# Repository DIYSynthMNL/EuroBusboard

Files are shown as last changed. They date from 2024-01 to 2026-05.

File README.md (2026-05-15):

# EuroBusboard

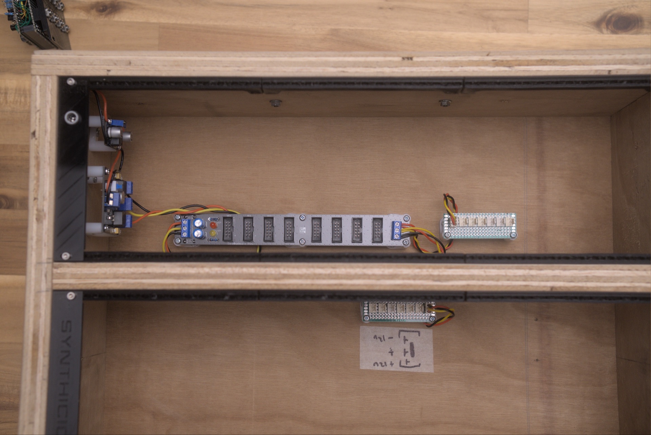
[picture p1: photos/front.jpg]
EuroBusboard installed in case


A Eurorack bus board with **8 module slots**, distributing **±12V + GND** across multiple connector formats. The project has three PCB variants in the same KiCad project: **10-pin IDC + JST combined**, **10-pin IDC only**, and **JST only**.

> For the Doepfer-standard 16-pin IDC variant (with `+5V`, `CV`, `Gate` rails additionally distributed), see the sibling repo: **[EuroBusboard-8-IDC-16PIN](https://github.com/DIYSynthMNL/EuroBusboard-8-IDC-16PIN)**.

## Variants

The KiCad project contains four configurations. Pick one when fabricating the PCB:

| Variant | KiCad file | Per-slot connectors | Use case |
|---|---|---|---|
| **16-pin IDC** (Doepfer A-100) | (in separate repo: [EuroBusboard-8-IDC-16PIN](https://github.com/DIYSynthMNL/EuroBusboard-8-IDC-16PIN)) | 1× 16-pin IDC | Modules with full Doepfer ribbon cables (±12V + GND + +5V + CV + Gate) |
| **10-pin IDC + JST (combined)** | `eurobusboard_idc_jst_8.kicad_pcb` | 1× 10-pin IDC + 1× 3-pin JST | Maximum flexibility — accepts both connector types per slot |
| **10-pin IDC only** | `eurobusboard_idc_8.kicad_pcb` | 1× 10-pin IDC | Compact, IDC-only modules |
| **JST only** | `eurobusboard_jst_8.kicad_pcb` | 1× 3-pin JST | DIY modules that use only the 3-pin JST power input |

All variants share the same power-input + reverse-protection + filter section. Only the per-slot connectors differ.

## Pinout (10-pin IDC, Eurorack subset of Doepfer A-100)

Looking at the IDC connector with the keyway (red stripe) on the *bottom*:

```
Pin   10  9   8   7   6   5   4   3   2   1
      +12 +12 GND GND GND GND GND GND -12 -12
```

`-12V` is on pin 1 / 2 (the red-stripe side) — Eurorack convention. `+12V` is on pin 9 / 10 (opposite side). Six GND pins in the middle provide low-impedance ground return.

The **3-pin JST** is:

| JST pin | Net |
|---|---|
| 1 | +12V |
| 2 | GND |
| 3 | -12V |

## Schematic

- Latest: **Rev 0.1** ([EuroBusboard-Schematic-rev0.1.pdf](Schematic%20PDFs/EuroBusboard-Schematic-rev0.1.pdf)) — 3 sheets, one per non-16-pin variant

## Power input / protection

Same circuit on all three sheets, just renamed nets per variant:

```
External ±12V supply
   │
   ├──[D3 / D14 / D9   1N4007 reverse-polarity diode on +12V]──┬── +12V bus
   │                                                            │
   │                                                            [C1 / C7 / C5   100µF bulk cap]
   │                                                            │
   │                                                            [D1 / D13 / D11  +12V indicator LED + R1/R7/R5 10K]
   │
   └──[D4 / D16 / D10  1N4007 reverse-polarity diode on -12V]──┬── -12V bus
                                                                │
                                                                [C2 / C8 / C6   100µF bulk cap]
                                                                │
                                                                [D2 / D15 / D12  -12V indicator LED + R2/R8/R6 10K]
```

Additional features (combined-variant only):
- **Power Thru** (J20, J21) — daisy-chain to another bus board
- **Test points** TP1 (+12V), TP2 (GND), TP3 (-12V) for DMM probing

## Design notes

**1N4007 diodes have a real voltage drop.** At a peak transient current of 1 A across each rail (with all 8 modules pulling momentarily), the diode drops about **1.0 V** — modules see only ~11 V on the rail instead of 12 V. For most analog modules this is harmless; for tight regulators (e.g. an LM7805 regulating to +5V from +12V supply that's actually 11V), it can reduce headroom. **A 1N5817 Schottky (~0.4 V drop)** would be a near-drop-in upgrade. See [issue](../../issues).

**No +5V or CV/Gate rails.** The 10-pin IDC variants don't distribute +5V (which most digital modules need) or CV/Gate (which the Doepfer A-100 standard provides for keyboard-bus signals). Modules requiring +5V must generate their own (via a 78M05 + the +12V rail — which is what most DIYSynthMNL modules do). For full Doepfer compatibility, use the 16-pin IDC variant in [EuroBusboard-8-IDC-16PIN](https://github.com/DIYSynthMNL/EuroBusboard-8-IDC-16PIN).

**Bulk capacitance.** 100 µF at the input is reasonable for a small case. For a fully-loaded board with current-hungry modules (digital sequencers, OLEDs, several VCAs), consider adding ~10 µF ceramics near each IDC connector for transient suppression.

## License

[GPLv3](LICENSE) — strong copyleft. **Note:** this is different from most DIYSynthMNL modules (which use CC-BY-NC-SA 4.0 for hardware, MIT for firmware). Confirm this license is intentional — for a passive bus board, MIT or CC-BY-SA may be more appropriate. See [issue](../../issues).

## Build status

What's ready for builders today, and what's still on the TODO list:

- [x] Schematic — Rev 0.1 ([EuroBusboard-Schematic-rev0.1.pdf](Schematic%20PDFs/EuroBusboard-Schematic-rev0.1.pdf))
- [ ] PCB layout — in progress — four variants in `kicad/`, no rev marker yet
- [ ] Gerber files for fabrication — none yet
- [ ] BOM — bus boards are simple; the schematic doubles as the BOM (LED color, diode replacement to Schottky if you take the recommendation above, etc.)
- [x] Photos of an assembled board — see [photos/](photos/)
- [x] License — [LICENSE](LICENSE) (GPLv3 — see note above)

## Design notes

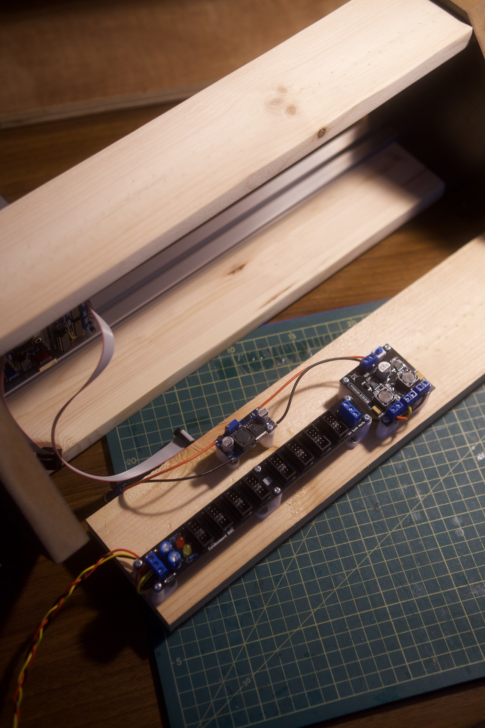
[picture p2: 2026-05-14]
photos/bench-4.jpg

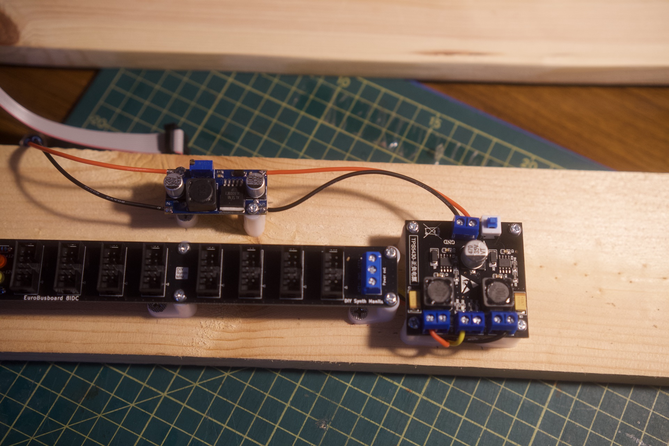
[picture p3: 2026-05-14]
photos/bench-with-psu.jpg

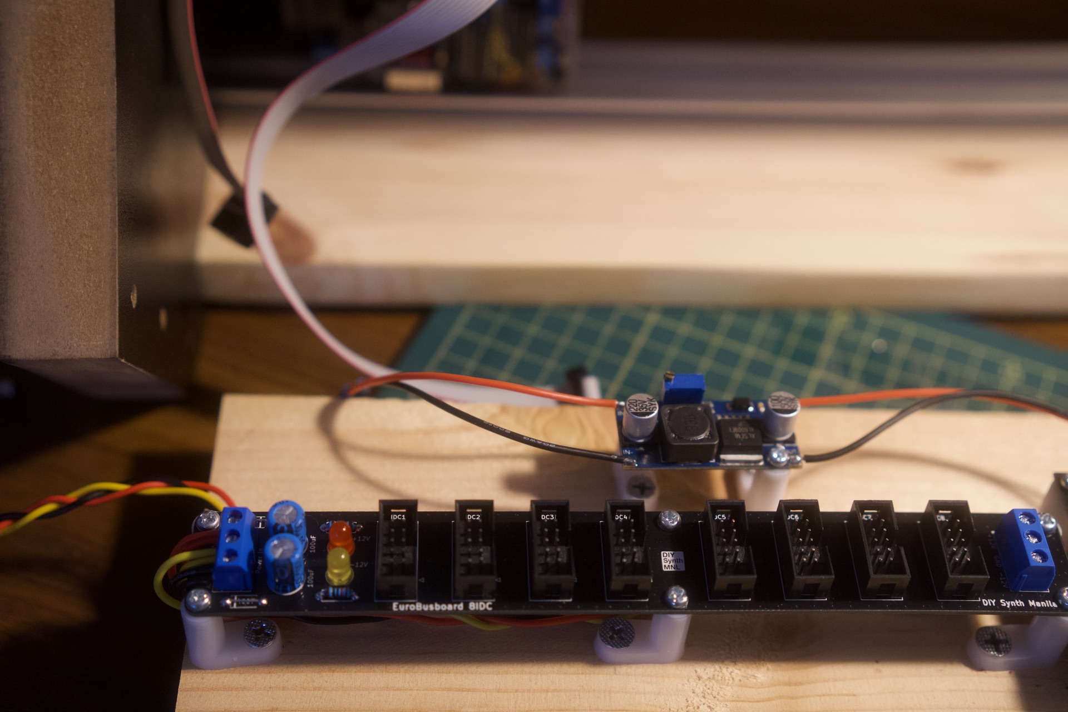
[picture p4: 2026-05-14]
photos/bench-3.jpg

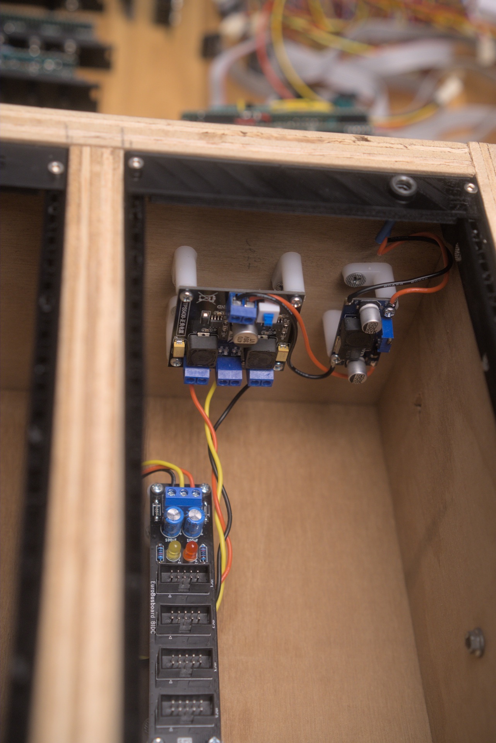
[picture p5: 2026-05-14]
photos/in-case-detail.jpg

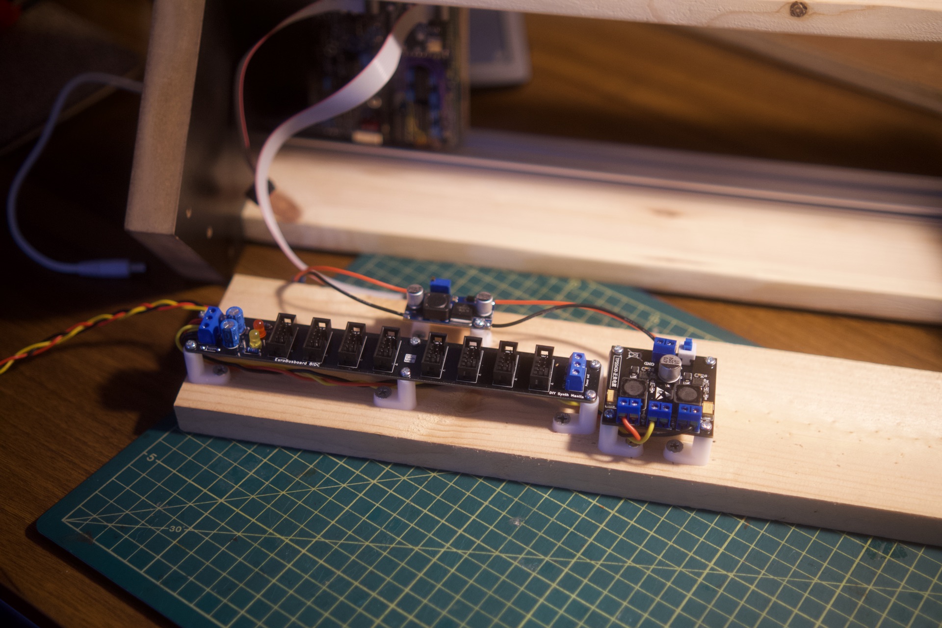
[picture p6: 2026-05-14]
photos/bench-1.jpg

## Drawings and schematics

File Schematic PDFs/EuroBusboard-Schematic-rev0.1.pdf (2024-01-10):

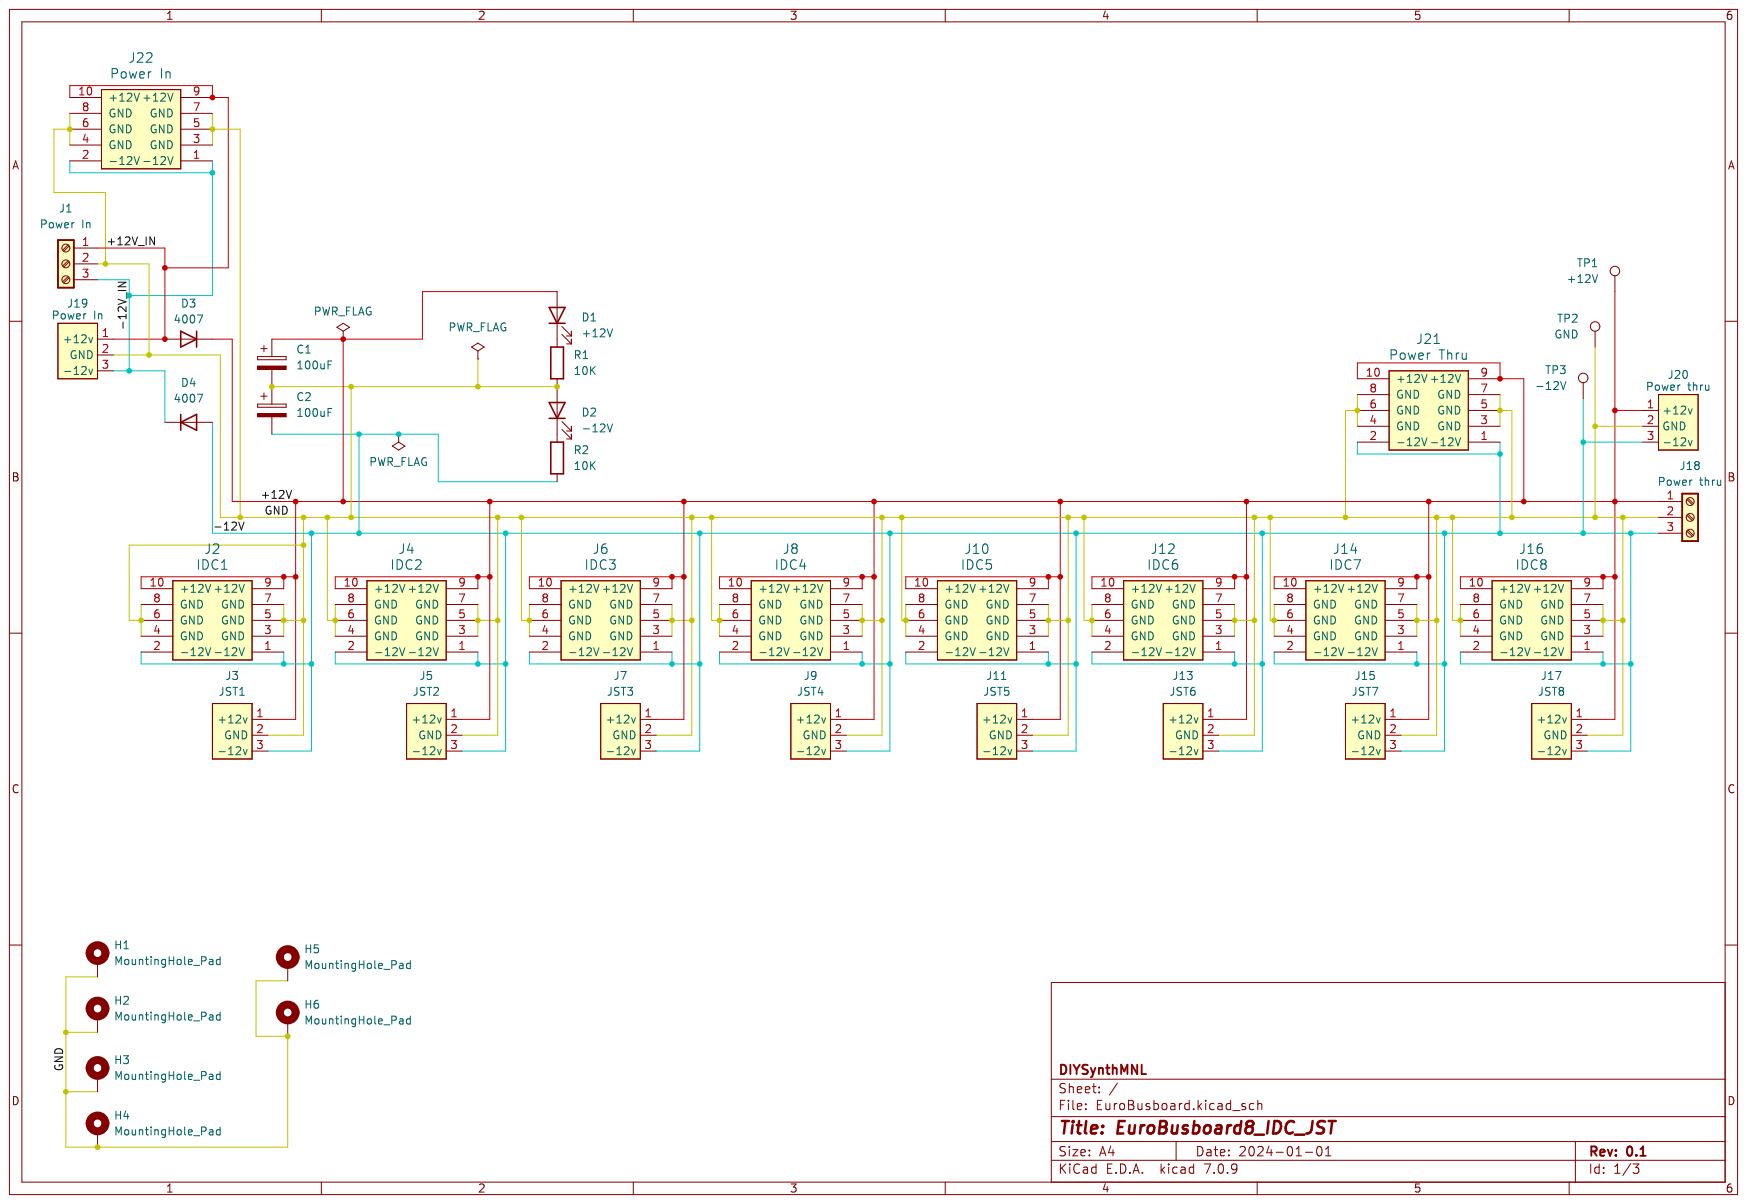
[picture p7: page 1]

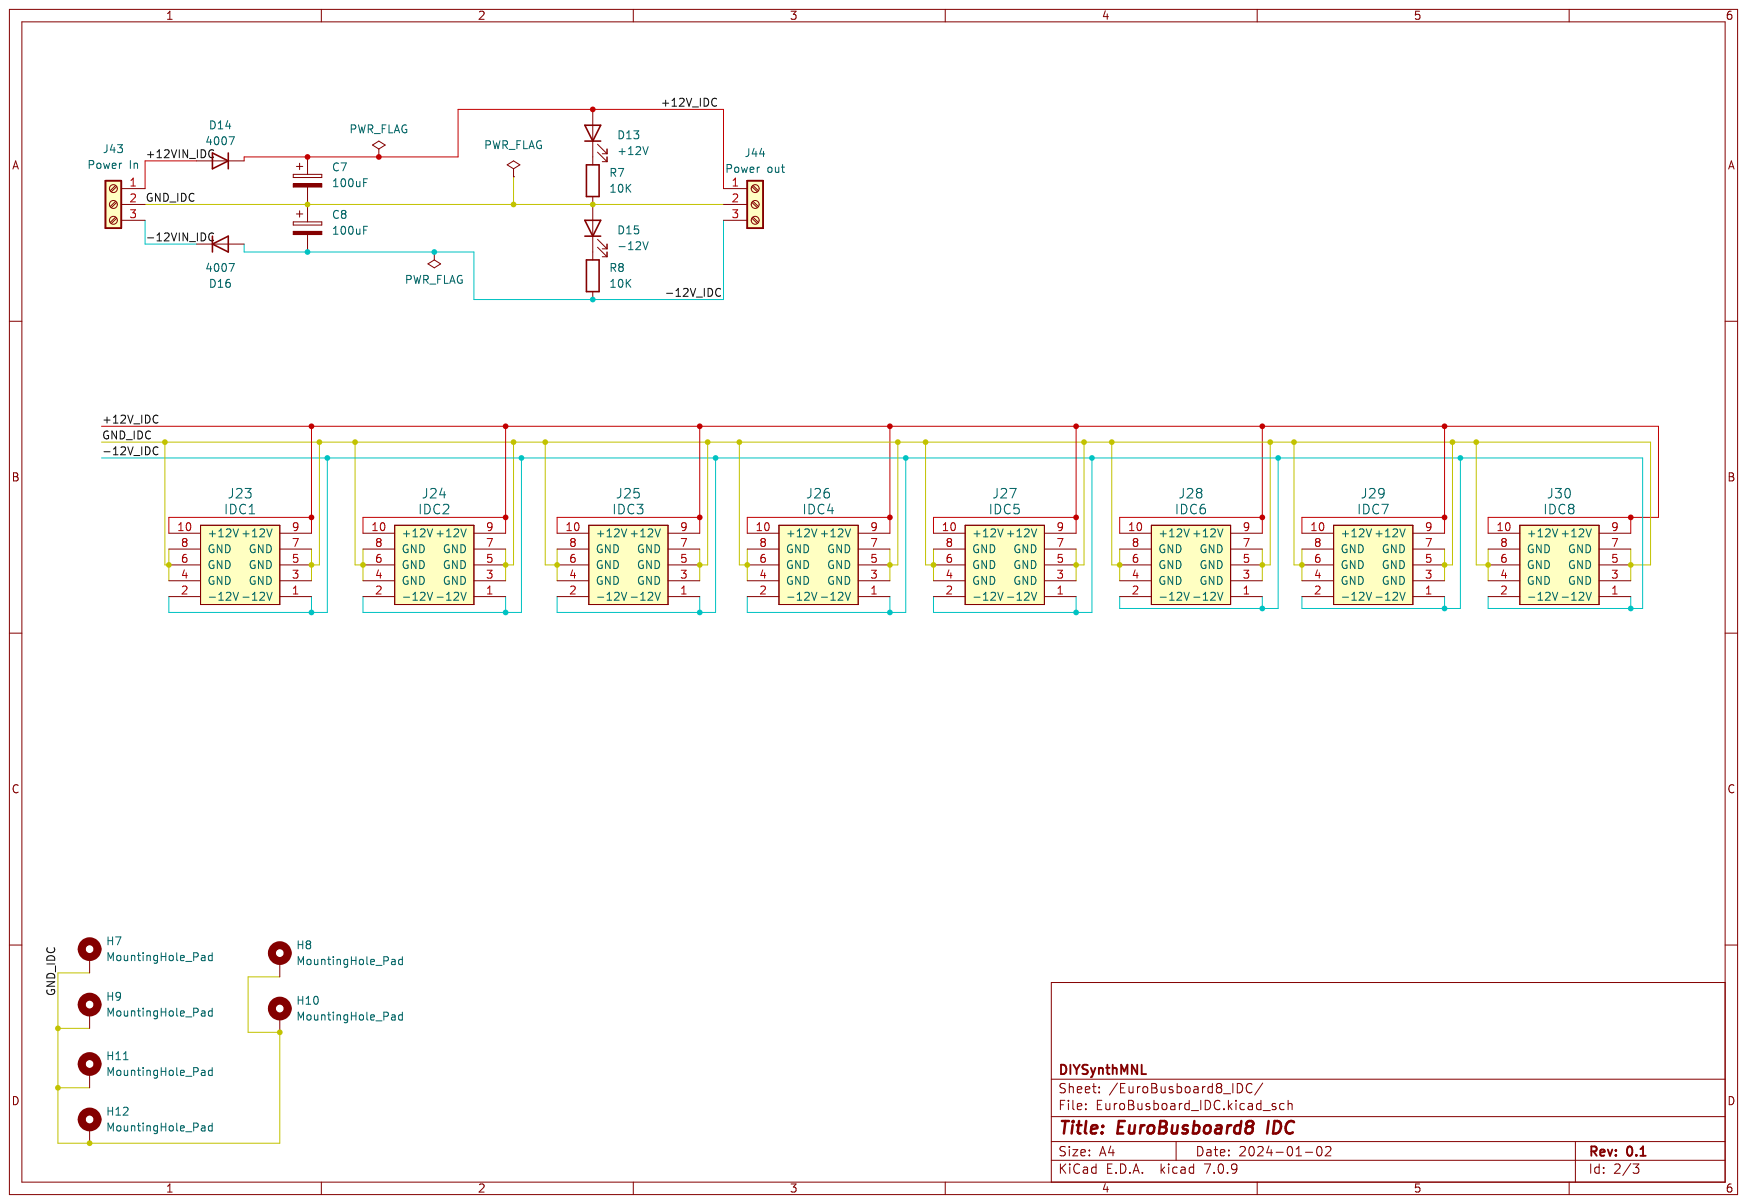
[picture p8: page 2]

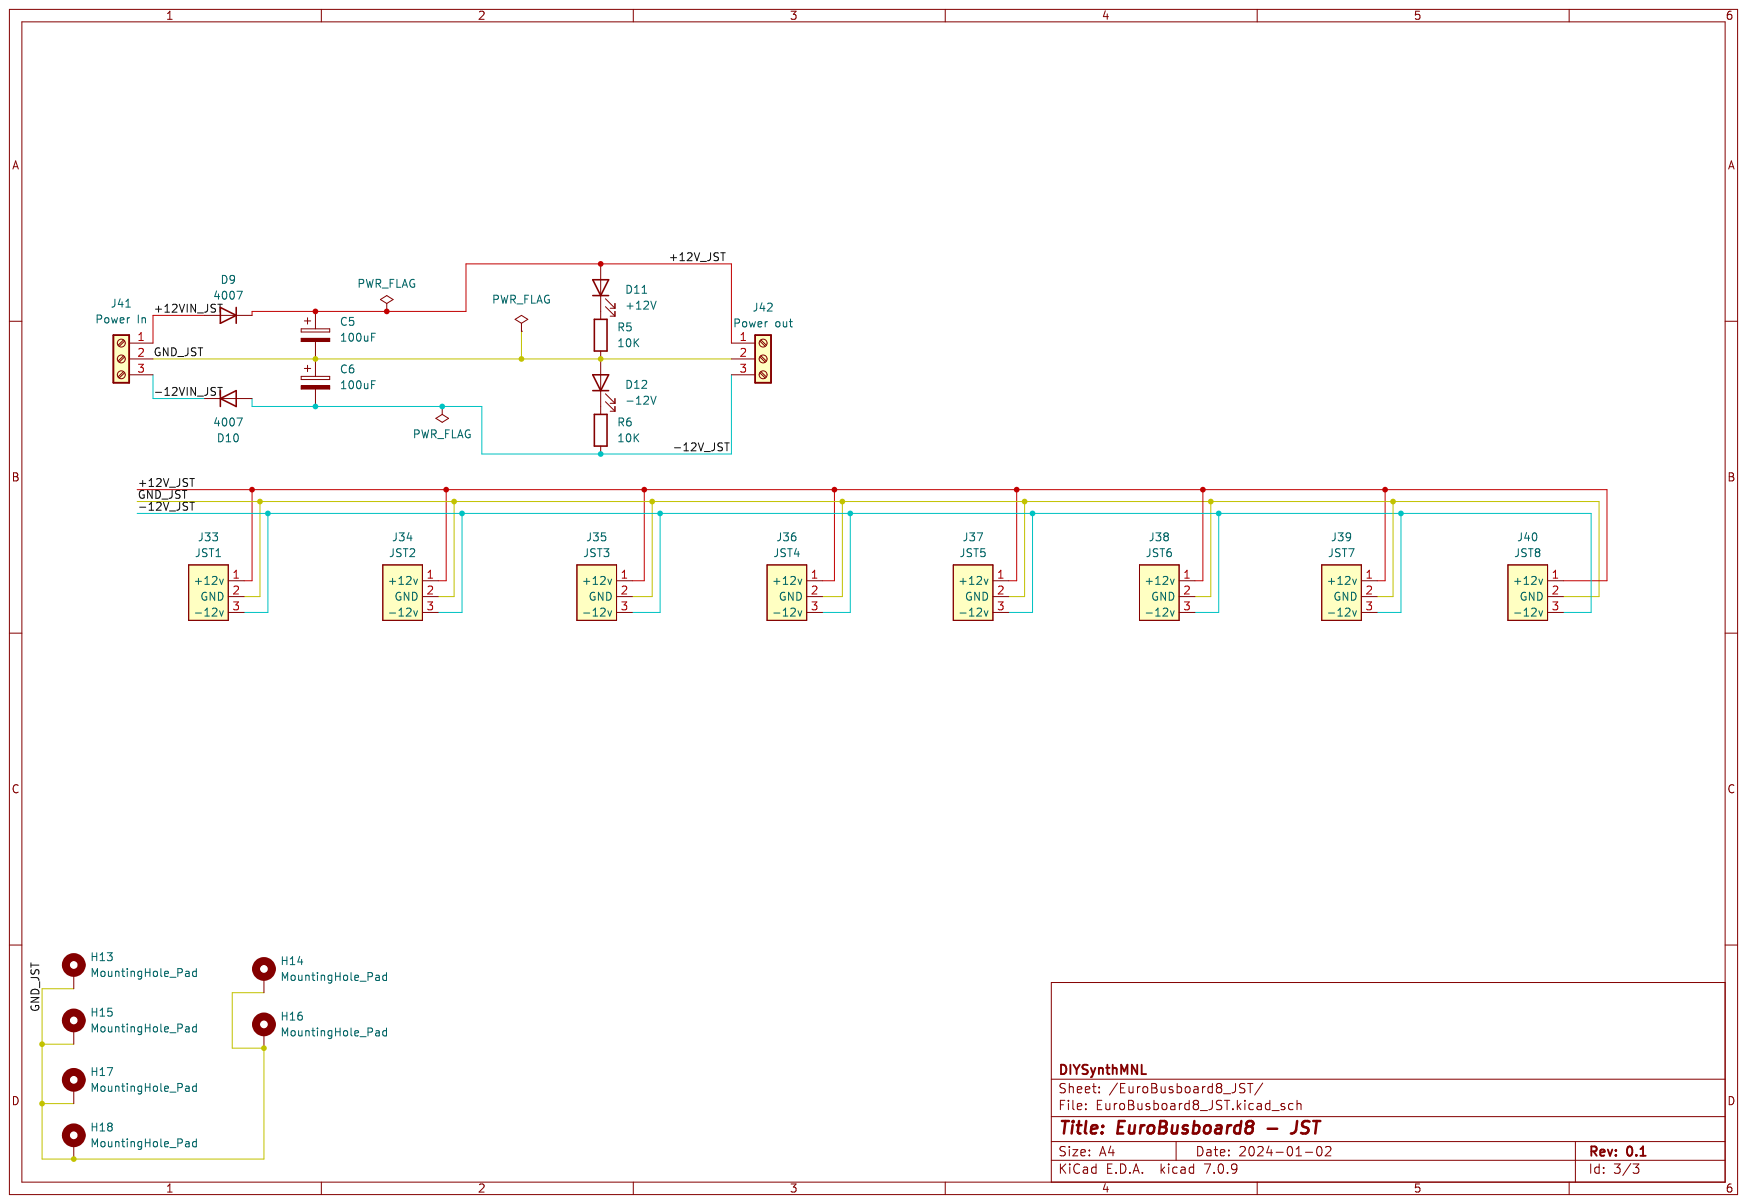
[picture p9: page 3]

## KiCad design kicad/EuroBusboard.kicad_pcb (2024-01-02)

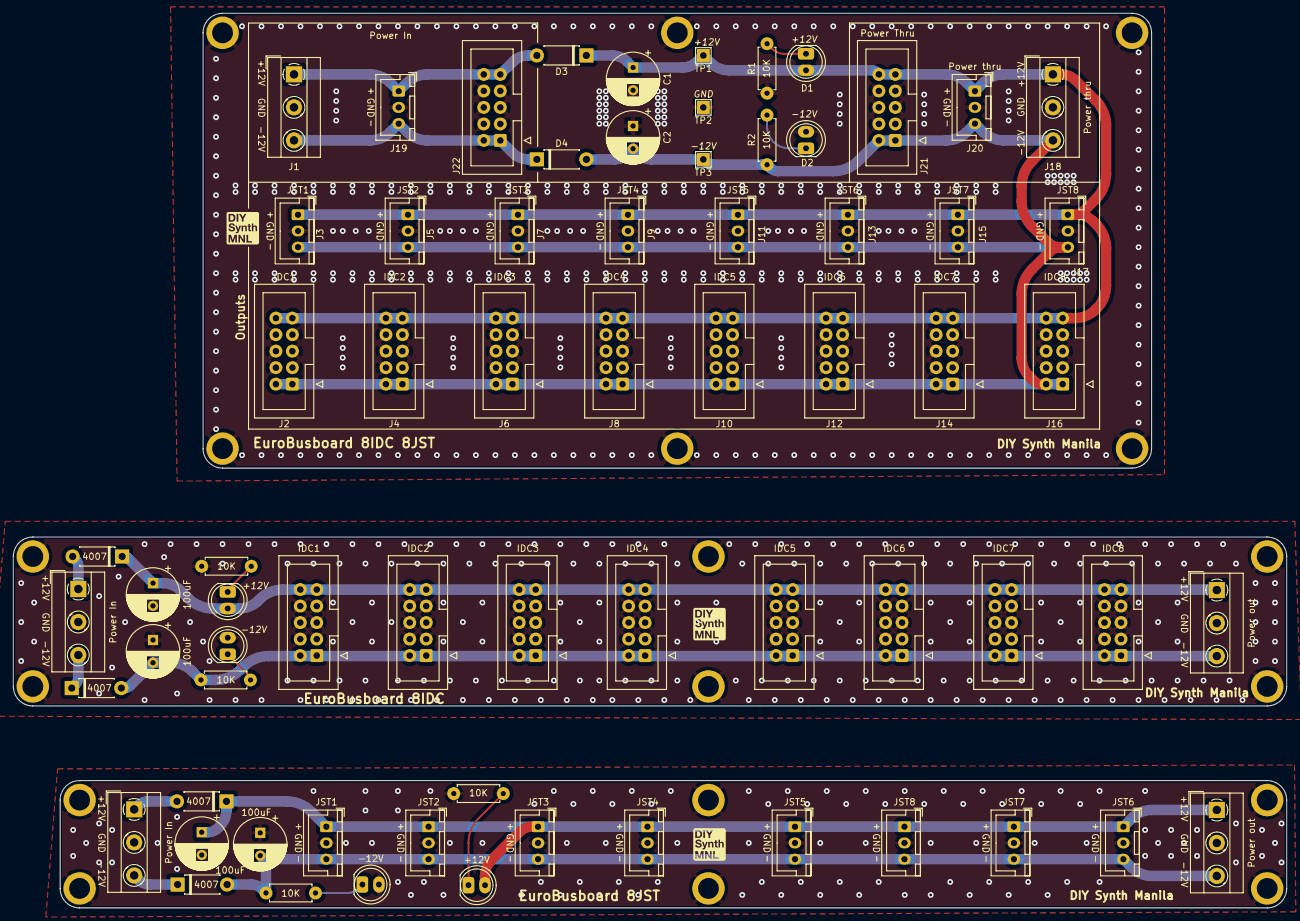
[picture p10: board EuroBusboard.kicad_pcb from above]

Board: 2 copper layers, 196.0 x 137.7 mm, 90 parts (0 on the bottom side), 21 nets.

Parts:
B1, B2, B3: Board
C1, C2, C5, C6, C7, C8: 100uF; CP_Radial_D8.0mm_P3.50mm
D1, D11, D13: +12V; LED_D5.0mm_BigPads
D2, D12, D15: -12V; LED_D5.0mm_BigPads
D3, D4, D9, D10, D14, D16: 4007; D_DO-41_SOD81_P7.62mm_Horizontal_BigPads
H1, H2, H3, H4, H5, H6, H7, H8, H9, H10, H11, H12, H13, H14, H15, H16, H17, H18: MountingHole_Pad; MountingHole_M3_Standoff_Pad
J1, J41, J43: Power In; TerminalBlock_MetzConnect_Type101_RT01603HBWC_1x03_P5.08mm_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
J2, J23: IDC1; IDC-Header_2x05_P2.54mm_Vertical_BigPads
J3, J33: JST1; Eurorack_power_jst_3P
J4, J24: IDC2; IDC-Header_2x05_P2.54mm_Vertical_BigPads
J5, J34: JST2; Eurorack_power_jst_3P
J6, J25: IDC3; IDC-Header_2x05_P2.54mm_Vertical_BigPads
J7, J35: JST3; Eurorack_power_jst_3P
J8, J26: IDC4; IDC-Header_2x05_P2.54mm_Vertical_BigPads
J9, J36: JST4; Eurorack_power_jst_3P
J10, J27: IDC5; IDC-Header_2x05_P2.54mm_Vertical_BigPads
J11, J37: JST5; Eurorack_power_jst_3P
J12, J28: IDC6; IDC-Header_2x05_P2.54mm_Vertical_BigPads
J13, J38: JST6; Eurorack_power_jst_3P
J14, J29: IDC7; IDC-Header_2x05_P2.54mm_Vertical_BigPads
J15, J39: JST7; Eurorack_power_jst_3P
J16, J30: IDC8; IDC-Header_2x05_P2.54mm_Vertical_BigPads
J17, J40: JST8; Eurorack_power_jst_3P
J18: Power thru; TerminalBlock_MetzConnect_Type101_RT01603HBWC_1x03_P5.08mm_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
J19: Power In; Eurorack_power_jst_3P
J20: Power thru; Eurorack_power_jst_3P
J21: Power Thru; IDC-Header_2x05_P2.54mm_Vertical_BigPads
J22: Power In; IDC-Header_2x05_P2.54mm_Vertical_BigPads
J42, J44: Power out; TerminalBlock_MetzConnect_Type101_RT01603HBWC_1x03_P5.08mm_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
R1, R2, R5, R6, R7, R8: 10K; R_quarter_watt_L6.3mm_D2.5mm_P7.62mm
TP1: +12V; TestPoint_THTPad_2.0x2.0mm_Drill1.0mm
TP2: GND; TestPoint_THTPad_2.0x2.0mm_Drill1.0mm
TP3: -12V; TestPoint_THTPad_2.0x2.0mm_Drill1.0mm

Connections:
/+12V: C1.1, D1.2 (A), D3.1 (K), J2.9 (+12V), J2.10 (+12V), J3.1 (+12v), J4.9 (+12V), J4.10 (+12V), J5.1 (+12v), J6.9 (+12V), J6.10 (+12V), J7.1 (+12v), J8.9 (+12V), J8.10 (+12V), J9.1 (+12v), J10.9 (+12V), J10.10 (+12V), J11.1 (+12v), J12.9 (+12V), J12.10 (+12V), J13.1 (+12v), J14.9 (+12V), J14.10 (+12V), J15.1 (+12v), J16.9 (+12V), J16.10 (+12V), J17.1 (+12v), J18.1, J20.1 (+12v), J21.9 (+12V), J21.10 (+12V), TP1.1
/+12V_IN: D3.2 (A), J1.1, J19.1 (+12v), J22.9 (+12V), J22.10 (+12V)
/-12V: C2.2, D4.2 (A), J2.1 (-12V), J2.2 (-12V), J3.3 (-12v), J4.1 (-12V), J4.2 (-12V), J5.3 (-12v), J6.1 (-12V), J6.2 (-12V), J7.3 (-12v), J8.1 (-12V), J8.2 (-12V), J9.3 (-12v), J10.1 (-12V), J10.2 (-12V), J11.3 (-12v), J12.1 (-12V), J12.2 (-12V), J13.3 (-12v), J14.1 (-12V), J14.2 (-12V), J15.3 (-12v), J16.1 (-12V), J16.2 (-12V), J17.3 (-12v), J18.3, J20.3 (-12v), J21.1 (-12V), J21.2 (-12V), R2.1, TP3.1
/-12V_IN: D4.1 (K), J1.3, J19.3 (-12v), J22.1 (-12V), J22.2 (-12V)
/EuroBusboard8_IDC/+12VIN_IDC: D14.2 (A), J43.1
/EuroBusboard8_IDC/+12V_IDC: C7.1, D13.2 (A), D14.1 (K), J23.9 (+12V), J23.10 (+12V), J24.9 (+12V), J24.10 (+12V), J25.9 (+12V), J25.10 (+12V), J26.9 (+12V), J26.10 (+12V), J27.9 (+12V), J27.10 (+12V), J28.9 (+12V), J28.10 (+12V), J29.9 (+12V), J29.10 (+12V), J30.9 (+12V), J30.10 (+12V), J44.1
/EuroBusboard8_IDC/-12VIN_IDC: D16.1 (K), J43.3
/EuroBusboard8_IDC/-12V_IDC: C8.2, D16.2 (A), J23.1 (-12V), J23.2 (-12V), J24.1 (-12V), J24.2 (-12V), J25.1 (-12V), J25.2 (-12V), J26.1 (-12V), J26.2 (-12V), J27.1 (-12V), J27.2 (-12V), J28.1 (-12V), J28.2 (-12V), J29.1 (-12V), J29.2 (-12V), J30.1 (-12V), J30.2 (-12V), J44.3, R8.1
/EuroBusboard8_IDC/GND_IDC: C7.2, C8.1, D15.2 (A), H7.1, H8.1, H9.1, H10.1, H11.1, H12.1, J23.3 (GND), J23.4 (GND), J23.5 (GND), J23.6 (GND), J23.7 (GND), J23.8 (GND), J24.3 (GND), J24.4 (GND), J24.5 (GND), J24.6 (GND), J24.7 (GND), J24.8 (GND), J25.3 (GND), J25.4 (GND), J25.5 (GND), J25.6 (GND), J25.7 (GND), J25.8 (GND), J26.3 (GND), J26.4 (GND), J26.5 (GND), J26.6 (GND), J26.7 (GND), J26.8 (GND), J27.3 (GND), J27.4 (GND), J27.5 (GND), J27.6 (GND), J27.7 (GND), J27.8 (GND), J28.3 (GND), J28.4 (GND), J28.5 (GND), J28.6 (GND), J28.7 (GND), J28.8 (GND), J29.3 (GND), J29.4 (GND), J29.5 (GND), J29.6 (GND), J29.7 (GND), J29.8 (GND), J30.3 (GND), J30.4 (GND), J30.5 (GND), J30.6 (GND), J30.7 (GND), J30.8 (GND), J43.2, J44.2, R7.1
/EuroBusboard8_JST/+12VIN_JST: D9.2 (A), J41.1
/EuroBusboard8_JST/+12V_JST: C5.1, D9.1 (K), D11.2 (A), J33.1 (+12v), J34.1 (+12v), J35.1 (+12v), J36.1 (+12v), J37.1 (+12v), J38.1 (+12v), J39.1 (+12v), J40.1 (+12v), J42.1
/EuroBusboard8_JST/-12VIN_JST: D10.1 (K), J41.3
/EuroBusboard8_JST/-12V_JST: C6.2, D10.2 (A), J33.3 (-12v), J34.3 (-12v), J35.3 (-12v), J36.3 (-12v), J37.3 (-12v), J38.3 (-12v), J39.3 (-12v), J40.3 (-12v), J42.3, R6.1
/EuroBusboard8_JST/GND_JST: C5.2, C6.1, D12.2 (A), H13.1, H14.1, H15.1, H16.1, H17.1, H18.1, J33.2 (GND), J34.2 (GND), J35.2 (GND), J36.2 (GND), J37.2 (GND), J38.2 (GND), J39.2 (GND), J40.2 (GND), J41.2, J42.2, R5.1
/GND: C1.2, C2.1, D2.2 (A), H1.1, H2.1, H3.1, H4.1, H5.1, H6.1, J1.2, J2.3 (GND), J2.4 (GND), J2.5 (GND), J2.6 (GND), J2.7 (GND), J2.8 (GND), J3.2 (GND), J4.3 (GND), J4.4 (GND), J4.5 (GND), J4.6 (GND), J4.7 (GND), J4.8 (GND), J5.2 (GND), J6.3 (GND), J6.4 (GND), J6.5 (GND), J6.6 (GND), J6.7 (GND), J6.8 (GND), J7.2 (GND), J8.3 (GND), J8.4 (GND), J8.5 (GND), J8.6 (GND), J8.7 (GND), J8.8 (GND), J9.2 (GND), J10.3 (GND), J10.4 (GND), J10.5 (GND), J10.6 (GND), J10.7 (GND), J10.8 (GND), J11.2 (GND), J12.3 (GND), J12.4 (GND), J12.5 (GND), J12.6 (GND), J12.7 (GND), J12.8 (GND), J13.2 (GND), J14.3 (GND), J14.4 (GND), J14.5 (GND), J14.6 (GND), J14.7 (GND), J14.8 (GND), J15.2 (GND), J16.3 (GND), J16.4 (GND), J16.5 (GND), J16.6 (GND), J16.7 (GND), J16.8 (GND), J17.2 (GND), J18.2, J19.2 (GND), J20.2 (GND), J21.3 (GND), J21.4 (GND), J21.5 (GND), J21.6 (GND), J21.7 (GND), J21.8 (GND), J22.3 (GND), J22.4 (GND), J22.5 (GND), J22.6 (GND), J22.7 (GND), J22.8 (GND), R1.1, TP2.1
unnamed: D1.1 (K), R1.2
unnamed: D2.1 (K), R2.2
unnamed: D11.1 (K), R5.2
unnamed: D12.1 (K), R6.2
unnamed: D13.1 (K), R7.2
unnamed: D15.1 (K), R8.2

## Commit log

2024-01-01 Schematic rev0.1 update
    [EuroBusboard.kicad_sch]
2024-01-02 PCB finished
    [EuroBusboard.kicad_pcb, EuroBusboard.kicad_sch]
2024-01-02 board update
    [EuroBusboard.kicad_pcb]
2024-01-02 added idc and jst only bus boards
    [EuroBusboard.kicad_pcb, EuroBusboard.kicad_sch, EuroBusboard8_JST.kicad_sch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]
2024-01-02 separated boards using kikit
    [eurobusboard_idc_8.kicad_pcb, eurobusboard_idc_jst_8.kicad_pcb, eurobusboard_jst_8.kicad_pcb]
2024-01-10 schematic pdf update
2024-01-22 added kicad gitignore
2024-01-27 cleaned up project directory
    [EuroBusboard.kicad_pcb, EuroBusboard.kicad_sch, EuroBusboard8_JST.kicad_sch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]
2026-05-14 Fix Build status link path case
2026-05-14 Add photos/ placeholder for assembled-module shots
2026-05-15 Deep-dive rewrite: README with variant matrix, pinout, design notes
    Restructures the README to clearly explain the 4 variants (16-pin IDC
    sibling, 10-pin IDC+JST combined, 10-pin IDC-only, JST-only), the
    Doepfer-subset pinout, and design notes about 1N4007 voltage drop
    and the absence of +5V/CV/Gate rails on the 10-pin variants.
    Flags the GPLv3 license as unusual for hardware (most open-hardware
    projects use CERN-OHL or CC-BY-SA) and recommends review.
    Filed 4 issues: Schottky upgrade, per-connector decoupling, license
    review, and possible merge with the 16-pin sibling repo.
